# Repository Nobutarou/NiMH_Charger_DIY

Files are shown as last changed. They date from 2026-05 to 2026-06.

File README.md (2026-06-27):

# v6.0 チョッパー式というのに挑戦してみる。(回路図と図面に間違いあり)

## 注意

RL78/G24 の SDA と SDL の位置を反対にしてしまっている。
v6.1 で修正するつもり。本作は、その場でなんとか配線し直した。

## 内容

v5.0 で考えたことは全部が無駄というわけでも無さそうだ。実は、ダイオードで、p-MOS が閉じて
いるときの電流を GND に長さずに回収して、入口に流しこむことで、効率が上がるらしい。チョッ
パー型の DCDC の原理だそうだ。回生エナジーを上手く使おうということだな。

ということで Falstad での練習が [こちら](./v6.0/falstad.txt)。
PWM は RL78/G24 を 16MHz 駆動にして 1000カウントで 16kHz で考えてる。2^n よりも多分、計算
しやすそうなので。

コイルはサガミ RTP8010-330M の予定。Falstad のコイルには抵抗は無いので自分で入れる。0.086
Ωとのこと。Elshop で TDK TSL1112RA-330K2R3 がセール対象で心魅かれるが、普段からほほコイル
を使ったことがなく33uH がどれくらい汎用性があるのかも分からないので、見送る。こちらの抵抗
は 標準値は不明だが最大で0.062Ω。サガミの 7313NC-330M は高性能だが、さすがにでかすぎる。

ショットキーは [11EQS03L](https://akizukidenshi.com/catalog/g/g108997/) で、逆飽和電流を
0.45V と 0.4V のときの T=25℃での電流値に、おおよそ合せ込んである。

pMOS は [2SJ334](https://akizukidenshi.com/goodsaffix/2sj334.pdf) で
βは単純な二次式による近似なので、データシートの全部に一致することはない。データシートは派
手な数値ばかり記載されているが、自分が欲しい 1A あたりのデータは、データシート 3ページ目の
左上 ID-VDS プロットである。ここから 

| VGS[V] | VDS[V] | ID[I] |
| --- | --- | --- |
| 2.5 | 0.135 | 1.0 |
| 3.0 | 0.06 | 1.0|

が得られる。Falstad の式では Vth 以下では電流が 0 になるので、ここはエイヤーで Vth=-1.4V
とした。それに対して β=8.35 となった。
[Falstad回路](./v6.0/2SJ334_falstad.txt)

一番右端のコンデンサは、パスコン。
ADC の C が 5pF と仮定する。インピーダンスは C に反比例。パスコンを入れて並列にしたら、そ
の比率でインピーダンスが低い方に流れる。

一方、ADC は 4096分解能。つまり,1波で 4096カウント分のノイズが入ったとしても、ノイズを
1/4096 まで減らせば 1カウントの誤差にまで減らせる。1/40960 まで減らせば 0.1 カウントだ。

そして 5pF の 40960倍 = 0.2uF だ。つまり 0.22uF で良いだろう。Falstad でも 0.1Ωのところの
電圧は安定しているように見える。そもそも ADC にパスコンなんて入れたこともないし、悪くなる
ことは無いだろう。

Fasltad で 1A を狙うようにデューティ比を調整しながら、電流や消費電力を測ってみた。
[計算シート](./v6.0/calc.gnumeric)

そしてDuty% (D), 電池電圧 (Vb), 電流(I) について、以下の近似式を得た。

```math
D = 87.382624  -26.930792 Vb -5.5315597 I 
``` 

今回 I=1A を狙っているので、

```math
D = 81.851064  -26.930792 Vb
```

が得られる。

どうせこの通りにはならないので、電流 (0.1Ωの電圧) が足りなければ 1カウント-, 越えてれば 1
カウント+ みたいに補正値を与えれば良いだろう。

[回路図](./v6.0/NiMHCharger6.0/NiMHCharger6.0_Schematics.pdf)

[設計図](./v6.0/NiMHCharger6.0.pdf)

部品表:

| 記号 | 品番、品目 | 個数 |
| --- | --- | --- |
| B1 | ユニバーサル基板 12x11P | 1 |
| B2 | ユニバーサル基板 15x10P | 1 |
| B2 | ユニバーサル基板  5x1P  | 1 |
| C1 | ケミコン 220uF | 1 |
| C2-4  | セラコン 0.22uF | 3 |
| D1 | ショットキー 1A 以上 | 1 |
| D2 | LED | 1 |
| H1 | 低背ヘッダ 2P | 1 |
| H2 | ヘッダ 5P | 1 |
| H3,4  | ヘッダ 3P | 2 |
| H5-7  | ヘッダ 1P | 3 |
| H8-10 | ヘッダ 2P | 3 |
| J1 | 電池ボックス 単三 基板用 | 1 |
| L1 | 33uH | 1 |
| Q1 | 2SJ334 pMOS | 1 |
| R1 | 0.1Ω 1% 0.25W 以上 | 1 |
| R2 | 100kΩ | 1 |
| R3,4  | 1kΩ | 1 |
| R5,6  | 300Ω | 1 |
| R7 | 2.7kΩか 1kΩか | 1 |
| S1 | プッシュスイッチ NKK の | 1 |
| S2 | ソケット 5P | 1 |
| TP1 | チェック端子 | 1 |
| U2 | TA76L431S | 1 |
| X1 | XH ポスト 2P | 1 |

## 結果

まずダメだったところ。3.3V では 5V の LCD は動かない。ソースは LCD の有無を選択できるよう
にした。

あと、マイコンの書き込みの時に配線つなぎ変えるのサボってやらかした。マザボがダメージを負っ
たらしく、USB の電圧がかなり落ちてしまった。この手の失敗は時々するので、USB ハブは別電源か
ら取れる準備をした方が良さそう。

それ以外は多分うまくいった。

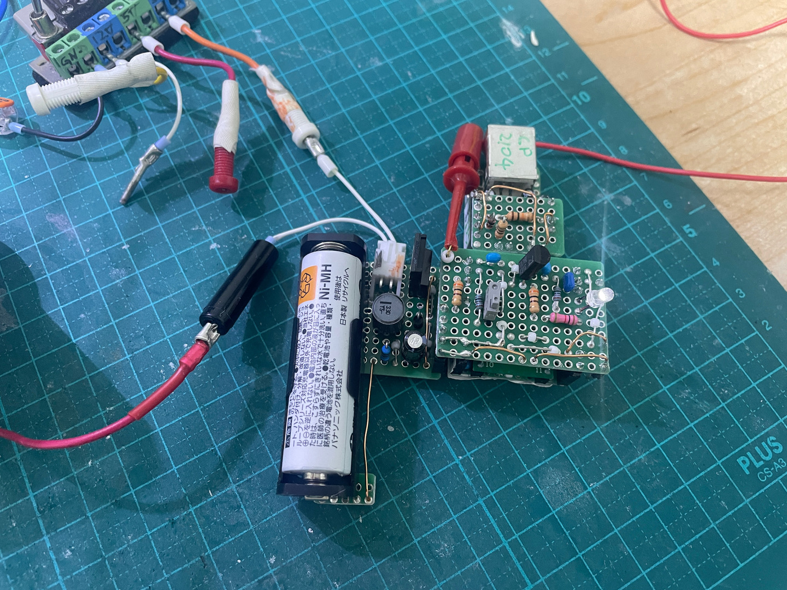
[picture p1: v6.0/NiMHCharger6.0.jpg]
完成品


電圧の垂れ下がりをうまくキャッチ。最序盤の急上昇の後の不安定さも移動平均でカバーできている
みたい。

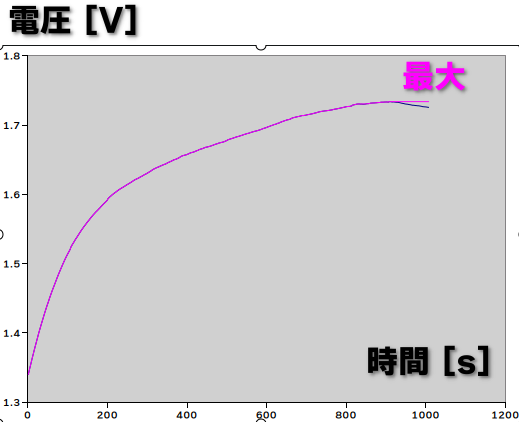
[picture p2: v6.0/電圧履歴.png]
電圧履歴


電流もおおよそ 1A をキープ。

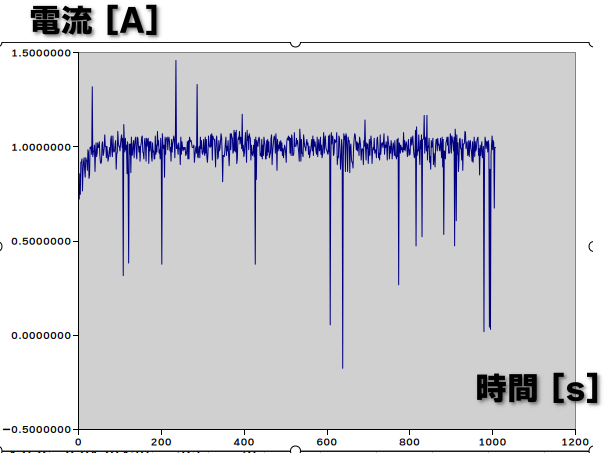
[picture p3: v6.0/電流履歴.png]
電流履歴


Duty の補正もまずまずの大きさ。Duty が振動してるのは、本来それだけ ADC の値が振動していた
ということ。移動平均が良い仕事をしたことが、ここからも分かる。

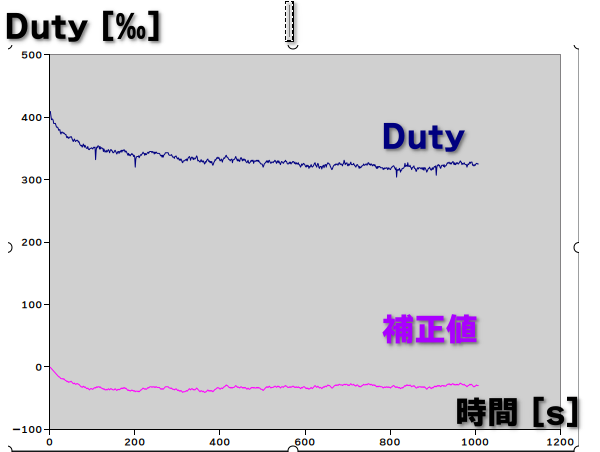
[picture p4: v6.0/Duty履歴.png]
Duty履歴


## ファームウェアの修正

電池によっては、初期の偽最大電圧からの下りを 84 秒以内にリカバリーできない。観察していると、
ガッと下がったあと、上昇基調で挽回しようとはするけど 84秒に到達という感じなので、一定回数、
10回とか、上昇基調が続いたら、偽最大電圧と判定して、その時点の電圧に最大値を置き換えるよう
にしてみる。

# v5.0 （没)
 <!--  {{{ -->
[こちら](https://github.com/Nobutarou/ArduinoDeAsobu/tree/main/NiMH_Charger)
で制作してきたが、リポジトリ自体がかなり大きくなってきたので、こっちに移った。そっちで検討
していた V4.0 は、なんだか苦労する割に報われない気がしたのでやめた。

v3.0 の改良を測ってみる。v3.0 の弱点は

- 充電中の電池電圧を測っていない
  - PWM でパチパチやってるときに、電圧測っちゃだめな気がしたため
- NchMOSFET を使ったため、電池の底の電圧を測定したが、多分これが精度低すぎ。
- 1A を狙ったが、実際には 70% くらいだった。

[こちら](https://github.com/Nobutarou/ArduinoDeAsobu/tree/main/LiIonCharger) 
ではリチウムイオン電池を充電してみたが、この時は PchMOSFET を使い、電池の頭の電圧を測定し
たが、値は安定しているように思う。

なので、今回は、PchMOSFET を使って LC フィルタで「まあこれなら電圧測っても大丈夫くらいだろ
う」と思える程度まで平滑化してみたい。平滑化するには PWM を極力高周波数で回すことが大事な
ので、RL78/G24 の最大32MHz 駆動で、99 または 255 カウントあたりの PWM, 周波数にして
125k-320kHz を使いたい。

li-ion のときの 
[2SJ334](https://akizukidenshi.com/goodsaffix/2sj334.pdf)
が 100kHz 台のパチパチに耐えられるかがポイント。

Vgs=-10V で Qg=110nC とあるので、Ciss=11000pF を採用したときのシミュレーションをする。
Falstad の P-mos の βは

```math
\beta = \frac{Y_{fs} }{Vgs-Vth}
```

Yfs が無いときは
```math
\beta = \frac{1}{R_{DS(on)} (V_{GS} - V_{th})}
```

でやってみると、そもそも理想状況でも全然電圧がでない。コイルは交流成分からしたら抵抗だから、
電圧がぐっと下がってどうにもならない。
https://x.gd/wddPF

そもそも構造的欠陥。

でコイルを止めてショットキーを入れるとなんか整流できてる。
https://x.gd/BBFU5

C で決まるローパスの周波数はこうらしい。手持ちだと 220uF が丁度良い感じ。PWM の切替えも数
百 usec で落ち着くかんじ。
```math
fc = \frac{1}{2 \pi R C}
```

で Ciss=11000pF 入れると全然だめ。オンにできないようだ。125kHz に落としてもどうにもならな
い。逆に 220uF は 125kHz でも良い感じでフィルタできる。

ところでダイオードを入れたが 0.47Ωの R を 2個の 0.22Ωに分けても良いみたいだ。ただどのみ
ち Ciss=11000pF ではどうにもならない。あと PWM を 64kHz とかにすると 220uF でも足りなくな
りがち。
https://x.gd/201CP

さて Ciss だけど実は Ciss(Vgs=0V)=3300pF, Ciss(Vgs=10V)=11000pF である。なので、3300pF で
成立しなかったら、もうどうにもならない。Ciss 無しで 1.65V くらいのようだが、3300pF を入れ
ると、1.42V くらいまで下がってしまう。

ただ 3.3V ではどうだろうか。Ciss(Vgs) は凸な関数と Gemini が言ってるので、なんとなく、
```math
a+b Vgs ^n
``` 
みたいな Johnson-cook な感じが合うような気がする。
次元がおかしいので Vgs は電圧ではなく、基準電圧との比率とすべきだが、細かいことはいいだろ
う。
a=Ciss(Vgs=0) で良いが b と n は分かりよ
うがないので、とりあえず n=0.5 とする。b=2435[pF] となる。
この仮定だと Ciss(Vgs=3.3V)=7723pF である。はい、全然だめ。

では 
[2SJ496](https://akizukidenshi.com/goodsaffix/2sj496.pdf) 
はどうだろうか。Yfs=5, Vth=2, Vgs(ID=2.5A)=2.7Vくらい（ID-Vgs プロットから) なので β=7.14
Ciss に最小値の 600pF の 2.34 倍, 1404pF を入力してみる。Qgs が載ってないから超適当.
で 1.4V くらいは出る。

だめだ。この方法は無理だ。最初の PWM を直接当ててる方がまだまし。

<!-- }}} -->

というか、何をどうしようが、3.3V 電源から 1A 流す時点で全体の消費電力は 3.3W。電池が 1V の
時は 2.3W を捨てて、電池が 1.5V のときは 1.8W を捨ててると言うこと。

P-mos から電池までの間をどうしようが、電力消費するパートがどれになるか変わるだけで、効率は
変わらない。

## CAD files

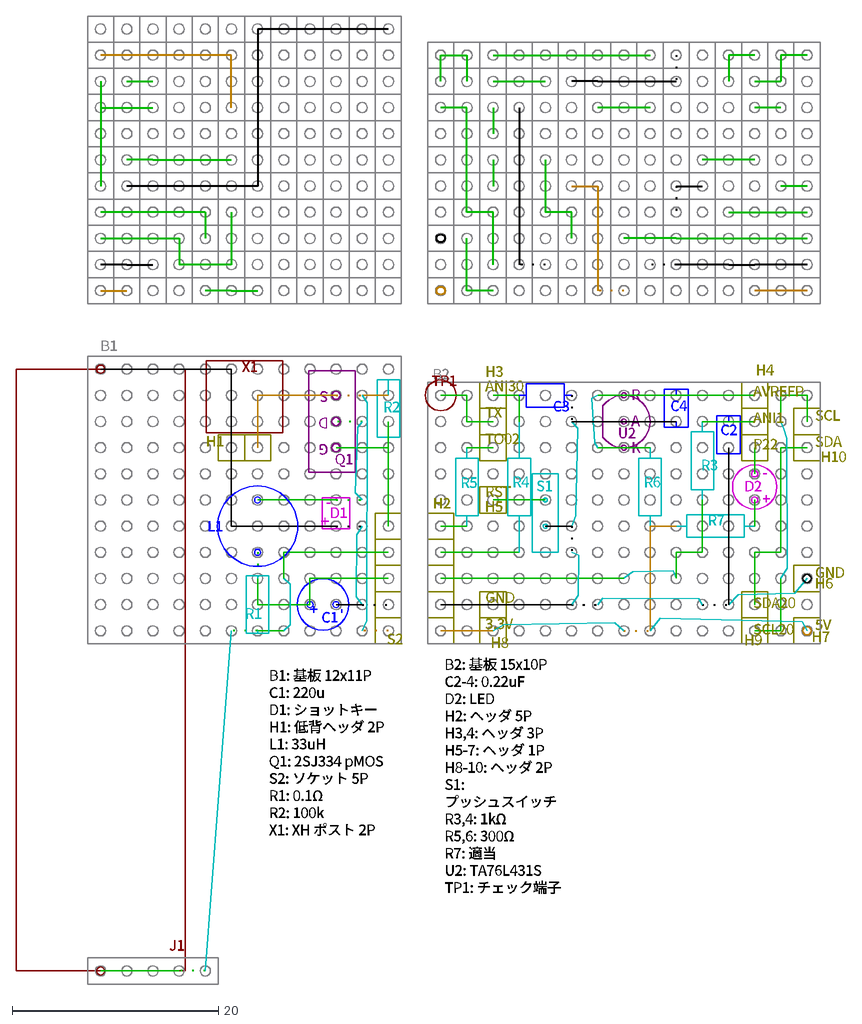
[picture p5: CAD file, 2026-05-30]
v6.0/NiMHCharger6.0.dxf
G D S
+
-
ANI30 TX TO02 RST GND 3.3V
R A K
- +
5V
GND
SDA
SCL
S1
B1
J1
X1
H1
L1
C1
D1
Q1
R2
H2
B2
H3
H4
H5
R5
U2
C4
R6
R3
C2
H6
H7
H8
H9
H10
R7
R1
R4
+ -
C3
TP1
AVREFP ANI1 P22 SDA20 SCL20
D2
B2: 基板 15x10P C2-4: 0.22uF D2: LED H2: ヘッダ 5P H3,4: ヘッダ 3P H5-7: ヘッダ 1P H8-10: ヘッダ 2P S1: プッシュスイッチ R3,4: 1kΩ R5,6: 300Ω R7: 適当 U2: TA76L431S TP1: チェック端子
S2
B1: 基板 12x11P C1: 220u D1: ショットキー H1: 低背ヘッダ 2P L1: 33uH Q1: 2SJ334 pMOS S2: ソケット 5P R1: 0.1Ω R2: 100k X1: XH ポスト 2P

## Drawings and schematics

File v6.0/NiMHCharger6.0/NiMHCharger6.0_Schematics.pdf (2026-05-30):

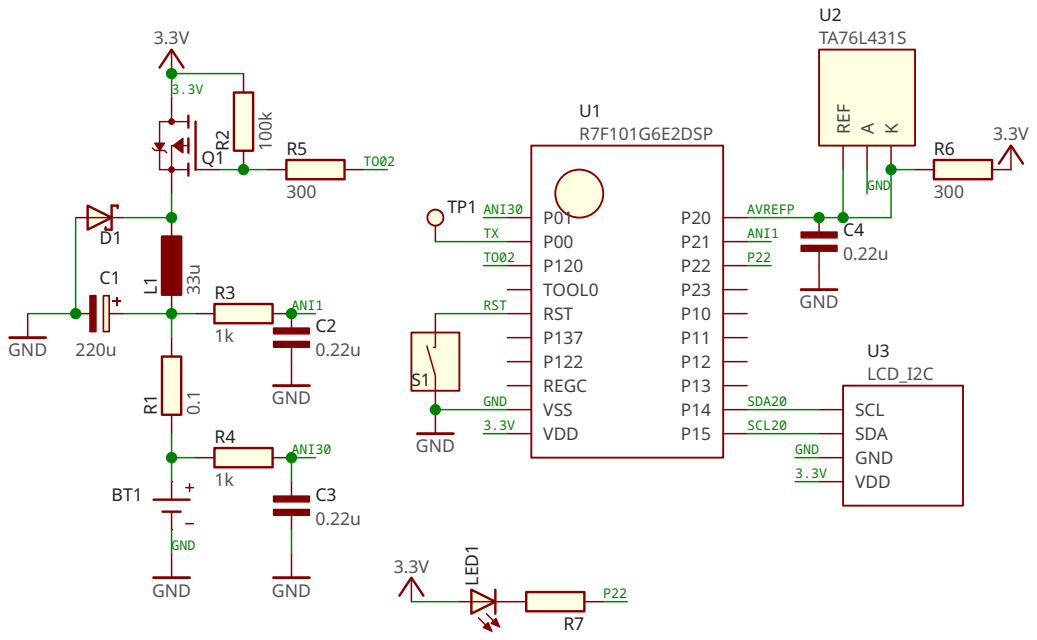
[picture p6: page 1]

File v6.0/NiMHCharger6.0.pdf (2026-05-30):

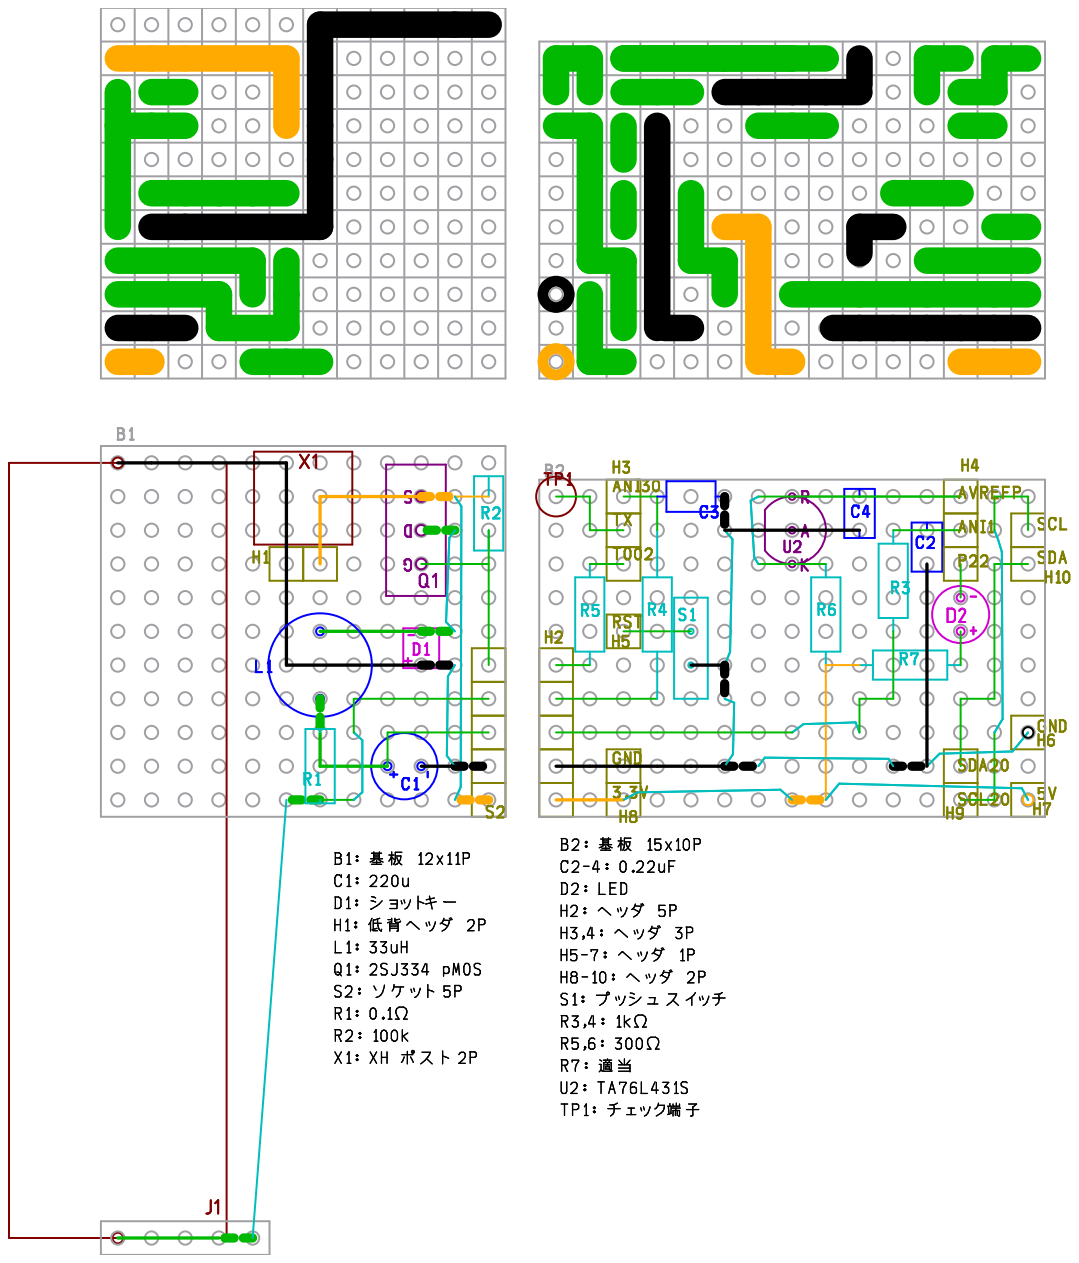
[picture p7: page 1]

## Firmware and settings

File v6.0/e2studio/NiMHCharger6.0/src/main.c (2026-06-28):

/*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
* Copyright (C) 2020 Renesas Electronics Corporation. All rights reserved.
***********************************************************************************************************************/

/***********************************************************************************************************************
*  File Name    : LCD_Hello.c
*  Description  : Main Program
*  Creation Date: 2025-10-12
*  This file was generated by Smart Configurator.
***********************************************************************************************************************/

#include "r_smc_entry.h"

int main(void);

// UART, I2C
volatile uint8_t _i2c_send_end; // 送信完了フラグ
volatile uint8_t _uart_end; 
#include "OreLCD.c" // _i2c_send_end と _uart_end は必要

#define DEBUG 1 //0: しない, 1: 軽く, 2: ガチ
#define USE_LCD 0 // 0: 未使用, 1:使う
// Gemini によると、最近のコンパイラは優秀なので static const でメモリを消費することは無い
// と言ってる。試しに #define ではなく static const で書いてみる。
// 可読性が良い気がする。
// それから static は、この .c でのみ有効という意味

static const float vref = 2.49; //ADC参照電圧
static const uint16_t pwm_count = 1000;
// 実際には 0-999 で一周期。RL78/G24 は 1000 を入れれば 100% になる。はず。

static const float duty_const = 81.851064; 
static const float tan_duty = -26.930792;
// D = 81.851064  -26.930792 Vb

static const uint8_t sub_count_max = 64;
// max712 の 1 サイクル 84 秒の間に行う子サイクルに相当

static const uint8_t main_count_max = 132*60/84;
// max712 は 132分でタイムオーバー。

static const uint16_t sub_wait_ms = 84000/64 ;
// max712 の 1サイクル[ms] に 2^sub_count_max 回、子サイクルを回すので、そのウェイト

static float rref = 0.1; //電圧測定抵抗 
static float sma_alfa = 1.0/64.0 ;//SMA移動平均の係数

static float current_target_upper = 1.02; //電流目標上限
static float current_target_lower = 0.98; //電流目標上限
// dI/dDuty[‰]=-0.018A。1A ターゲットなら、おおよそ 2%

// 移動平均電圧が、この回数連続で上昇したら、その最大電圧は序盤の偽最大値と判断して、その
// 時点の移動平均電圧に置き換える。
// 10 だと厳しすぎた感じ。
// static uint8_t nise_max_kaijo_count =5;
// これを使わない方法にしてみた。

int main(void)
{
  float vbat; //電池電圧
  float vbat_sma; //電池電圧 SMA 移動平均
  float vbat_sma_max; // SMA最大値
  int duty; //PWM Duty。計算の都合上 int にしておく
  
  uint8_t sub_count = 1;
  //max712 での 1サイクル内でのカウント
  //便宜上 1から始める
  uint8_t main_count = 1;

  float vr; //抵抗電圧
  float current; //電流

  uint8_t flag_max=0; 
  //最大電圧更新フラグ. 1 で更新

  int duty_hosei=0; //Duty の補正オフセット量

  // 偽 max を判定するための、vbat_sma 連続上昇回数カウント
  //uint8_t renzoku_up_count = 0;
  float vbat_sma_pre; //電池電圧 SMA 移動平均、1サイクル前

  EI();

  // LED 点灯
  // プルアップなので 0 で点灯
  P2_bit.no2 = 0;

  // PWM を開始。コンフィグレータで 1000‰に指定してある。
  R_Config_TAU0_0_Start()  ;

  #if DEBUG >= 1
  R_Config_UART1_Start();
  // OreUART1_Send_ASCII('S'); // OK
  #endif 

  #if USE_LCD == 1
  OreLCDBegin();    
  #endif 

  #if DEBUG >= 1
  //OreUART1_Send_ASCII('L'); // NG
  //OreUART1_Send_CRLF();
  // SDA と SCL を逆にしてしまう大失敗。--> 直した
  // なぜかここに戻ってきてしまう。
  #endif 

  // ADC 空打ち
  // なんか起動直後の 1回目は変な値を取る気がする。
  // コンフィグレータ設定ピンは ANI30
  R_Config_ADC_Start();
  while(ADCS==1){};
  R_Config_ADC_Stop();
  // ANI1 に切り替えて空打ち
  R_Config_ADC_Set_ADChannel (ADCHANNEL1);
  R_Config_ADC_Start();
  while(ADCS==1){};
  R_Config_ADC_Stop();
  // ANI30 に戻す
  R_Config_ADC_Set_ADChannel (ADCHANNEL30);

  // ここからが本番
  // ADC の測定
  // 今 ANI30, 電池になってる
  R_Config_ADC_Start();
  while(ADCS==1){};
  R_Config_ADC_Stop();
  vbat = vref * ( (float)ADCR0+0.5 )/4096.0;
  // 回してる最中なら ANI1 に切り替えて抵抗の電圧を測定するが 1回目なので何もしない。
  
  // 最初の計測値で SMA 電圧を埋めておく。一回目だけ。
  vbat_sma = vbat;
  vbat_sma_max = vbat_sma;

  // 目標Duty の決定
  duty = (int)( (duty_const + tan_duty * vbat)/100.0 * (float)(pwm_count) ) ;
  if (duty > pwm_count){ 
    duty = pwm_count;
  } else if (duty < 0){
    duty = 0;
  }
  TDR02=(uint16_t)duty;

  // 電池電圧、電流、Duty補正をUART に出すことにしておこう。

  // LCD も同様
  #if USE_LCD == 1
  OreLCD_Char(0b01010110); //"V"
  OreLCD_Char(0b00111010); //":"
  OreLCD_Fixed(vbat, 4);
  OreLCD_Locate(1,0); //二行目
  OreLCD_Char(0b01001001); //"I"
  OreLCD_Char(0b00111010); //":"
  #endif 

  #if DEBUG >= 1
  // ここは表示される。
  OreUART1_Send_Float(vbat_sma, 8);
  OreUART1_Send_ASCII(',');
  OreUART1_Send_CRLF();
  #endif 

  //sub_count=sub_count+1; 

  R_BSP_SoftwareDelay(sub_wait_ms, BSP_DELAY_MILLISECS);

  // これで子サイクルの 1回目が終わった。

  // メインサイクル
  for(; main_count <= main_count_max; main_count++){
    // サブサイクル
    for (; sub_count <= sub_count_max; sub_count++){
      //{{{
      //電池電圧測定
      R_Config_ADC_Set_ADChannel (ADCHANNEL30);
      R_Config_ADC_Start();
      while(ADCS==1){};
      R_Config_ADC_Stop();
      vbat = vref * ( (float)ADCR0+0.5 )/4096.0;
    
      //抵抗電圧測定
      R_Config_ADC_Set_ADChannel (ADCHANNEL1);
      R_Config_ADC_Start();
      while(ADCS==1){};
      R_Config_ADC_Stop();
      vr = vref * ( (float)ADCR0+0.5 )/4096.0;

      //移動平均、最大値チェック
      vbat_sma_pre = vbat_sma;
      vbat_sma = vbat * sma_alfa + (1.0-sma_alfa) * vbat_sma;
      
      //if (vbat_sma > vbat_sma_max){
      //// 最大値更新したとき
      //  vbat_sma_max = vbat_sma;
      //  flag_max = 1;
      //  renzoku_up_count = 0;
      //} else if (vbat_sma > vbat_sma_pre) {
      //// 最大値は更新しなかったが、vbat_sma 自体は 1サブサイクル前を越えてる場合
      //  renzoku_up_count = renzoku_up_count + 1;
      //  if (renzoku_up_count >= nise_max_kaijo_count){
      //  // 連続 nise_max_kaijo_count 回の上昇を示したら
      //    vbat_sma_max = vbat_sma;
      //    flag_max = 1;
      //    renzoku_up_count = 0;
      //  };
      //} else {
      //// 最大値も更新しないし vbat_sma も前サイクルに及ばないなら
      //  renzoku_up_count = 0;
      //}

      // 更新しなくても上昇していれば vbat_sma_max を現在地との平均値とする。
      if (vbat_sma > vbat_sma_max){
      // 最大値更新したとき、そのまま置き換え。
        vbat_sma_max = vbat_sma;
        flag_max = 1;
      } else if (vbat_sma > vbat_sma_pre) {
      // 最大値は更新しなかったが、vbat_sma 自体は 1サブサイクル前を越えてる場合
          vbat_sma_max = 0.5*vbat_sma + 0.5*vbat_sma_max;
      };

      //電流計算
      current = (vr-vbat)/rref;

      // dI/dDuty = -0.18 A/duty[%] = -0.018A/duty[‰]
      // つまり 0.018A のずれが無ければ、duty を触る価値はない
      // ざっくり 2% で見ておけばいいだろう。
      if (current > current_target_upper){
        duty_hosei=duty_hosei+1;
      } else if (current < current_target_lower ){
        duty_hosei=duty_hosei-1;
      };

      // 今回から duty に補正を掛ける
      duty = (int)( (duty_const + tan_duty * vbat)/100.0 * (float)(pwm_count) ) + duty_hosei ;
      if (duty > pwm_count){ 
        duty = pwm_count;
      } else if (duty < 0){
        duty = 0;
      }

      TDR02=(uint16_t)duty;

      #if DEBUG >= 1
      // 途中で current を出力できなくなる
      OreUART1_Send_Float(vbat_sma, 8);
      OreUART1_Send_ASCII(',');
      OreUART1_Send_Float(vbat_sma_max, 8);
      OreUART1_Send_ASCII(',');
      //OreUART1_Send_Float(vbat, 8);
      //OreUART1_Send_ASCII(',');
      //OreUART1_Send_Float(vr, 8);
      //OreUART1_Send_ASCII(',');
      // なんか知らんけど current止まる. 
      OreUART1_Send_Float(current, 7);
      OreUART1_Send_ASCII(',');
      OreUART1_Send_U16( (uint16_t)duty);
      OreUART1_Send_ASCII(',');
      if( duty_hosei < 0){
        OreUART1_Send_ASCII('-');
        OreUART1_Send_U16( (uint16_t)(-duty_hosei) );
      } else {
        OreUART1_Send_U16( (uint16_t)(duty_hosei) );
      }
      OreUART1_Send_CRLF();
      #endif 

      // LCD も同様
      #if USE_LCD == 1
      OreLCD_CLS();
      OreLCD_Char(0b01010110); //"V"
      OreLCD_Char(0b00111010); //":"
      OreLCD_Fixed(vbat, 4);
      OreLCD_Locate(1,0); //二行目
      OreLCD_Char(0b01001001); //"I"
      OreLCD_Char(0b00111010); //":"
      OreLCD_Fixed(current, 4);
      #endif
      R_BSP_SoftwareDelay(sub_wait_ms, BSP_DELAY_MILLISECS);
    /* }}} */
    };
    if(flag_max == 0){
      TDR02=pwm_count;
      while(1){
         // LED チカチカ
         P2_bit.no2 = !P2_bit.no2;
         R_BSP_SoftwareDelay(1, BSP_DELAY_SECS);
      };
    }
    sub_count=1;
    flag_max = 0;
  }

  // メインカウント乗り越えたら
  TDR02=pwm_count;
  while(1){
     // LED チカチカ
     P2_bit.no2 = !P2_bit.no2;
     R_BSP_SoftwareDelay(2, BSP_DELAY_SECS);
  };
  return 0;
}

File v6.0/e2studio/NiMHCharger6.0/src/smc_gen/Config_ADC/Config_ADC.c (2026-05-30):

/*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
* Copyright (C) 2021, 2025 Renesas Electronics Corporation. All rights reserved.
***********************************************************************************************************************/

/***********************************************************************************************************************
* File Name        : Config_ADC.c
* Component Version: 1.8.0
* Device(s)        : R7F101G6ExSP
* Description      : This file implements device driver for Config_ADC.
***********************************************************************************************************************/

/***********************************************************************************************************************
Pragma directive
***********************************************************************************************************************/
/* Start user code for pragma. Do not edit comment generated here */
/* End user code. Do not edit comment generated here */

/***********************************************************************************************************************
Includes
***********************************************************************************************************************/
#include "r_cg_macrodriver.h"
#include "r_cg_userdefine.h"
#include "Config_ADC.h"
/* Start user code for include. Do not edit comment generated here */
/* End user code. Do not edit comment generated here */

/***********************************************************************************************************************
Global variables and functions
***********************************************************************************************************************/
/* Start user code for global. Do not edit comment generated here */
/* End user code. Do not edit comment generated here */

/***********************************************************************************************************************
* Function Name: R_Config_ADC_Create
* Description  : This function initializes the ADC module.
* Arguments    : None
* Return Value : None
***********************************************************************************************************************/
void R_Config_ADC_Create(void)
{
    ADCEN = 1U;    /* supply AD clock */
    ADMK0 = 1U;    /* disable INTAD0 interrupt */
    ADIF0 = 0U;    /* clear INTAD0 interrupt flag */
    /* Set INTAD0 priority */
    ADPR10 = 1U;
    ADPR00 = 1U;
    /* Set ANI30 pin */
    PMCA0 |= 0x02U;
    PM0 |= 0x02U;
    /* Set AVREFP pin */
    PMCA2 |= 0x01U;
    PM2 |= 0x01U;
    ADM0 = _00_AD_OPERMODE_SELECT | _18_AD_CONVERSION_CLOCK_4 | _00_AD_TIME_MODE_NORMAL_1;
    ADM1 = _00_AD_TRIGGER_SOFTWARE | _00_AD_FCLK_BETWEEN_4_48 | _20_AD_CONVMODE_ONESELECT;
    ADM2 = _00_AD_NEGATIVE_VSS | _00_AD_AREA_MODE_1 | _02_AD_RESOLUTION_12BIT;
    ADUL = _FF_AD_ADUL_VALUE;
    ADLL = _00_AD_ADLL_VALUE;
    ADS = _1E_AD_INPUT_CHANNEL_30;
    ADM2 &= _3F_AD_POSITIVE_CLEAR;    /* clear ADREFP1 and ADREFP0 */
    ADM2 |= _40_AD_POSITIVE_AVREFP;    /* set the reference voltage */

    R_Config_ADC_Create_UserInit();
}

/***********************************************************************************************************************
* Function Name: R_Config_ADC_Start
* Description  : This function starts the AD converter.
* Arguments    : None
* Return Value : None
***********************************************************************************************************************/
void R_Config_ADC_Start(void)
{
    ADIF0 = 0U;    /* clear INTAD0 interrupt flag */
    ADMK0 = 0U;    /* enable INTAD0 interrupt */
    ADCS = 1U;    /* enables conversion operation */
}

/***********************************************************************************************************************
* Function Name: R_Config_ADC_Stop
* Description  : This function stops the AD converter.
* Arguments    : None
* Return Value : None
***********************************************************************************************************************/
void R_Config_ADC_Stop(void)
{
    ADCS = 0U;    /* stops conversion operation */
    ADMK0 = 1U;    /* disables INTAD0 interrupt */
    ADIF0 = 0U;    /* clear INTAD0 interrupt flag */
}

/***********************************************************************************************************************
* Function Name: R_Config_ADC_Set_OperationOn
* Description  : This function enables AD voltage comparator operation.
* Arguments    : None
* Return Value : None
***********************************************************************************************************************/
void R_Config_ADC_Set_OperationOn(void)
{
    volatile uint16_t w_count;

    ADCE = 1U;    /* enable AD comparator */

    /* Reference voltage stability wait time (B) 1us */
    for (w_count = 0U; w_count < AD_WAITTIME_B; w_count++ )
    {
        NOP();
    }
}
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

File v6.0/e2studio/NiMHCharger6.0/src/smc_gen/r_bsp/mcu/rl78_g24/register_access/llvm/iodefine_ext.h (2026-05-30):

/*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
* Copyright (C) 2023 Renesas Electronics Corporation. All rights reserved.
***********************************************************************************************************************/
/***********************************************************************************************************************
* File Name    : iodefine_ext.h
* Description  : 
***********************************************************************************************************************/
/***********************************************************************************************************************
* History : DD.MM.YYYY Version  Description
*         : 28.02.2023 1.60     First Release.
*         : 30.11.2023 1.62     Updated device file.
***********************************************************************************************************************/

#ifndef __INTRINSIC_FUNCTIONS
#define __INTRINSIC_FUNCTIONS

#define DI() __builtin_rl78_di()
#define EI() __builtin_rl78_ei()
#define HALT() __halt()
#define NOP() __nop()
#define STOP() __stop()

#endif

#ifndef __IOREG_BIT_STRUCTURES
#define __IOREG_BIT_STRUCTURES
typedef struct {
	unsigned char no0 :1;
	unsigned char no1 :1;
	unsigned char no2 :1;
	unsigned char no3 :1;
	unsigned char no4 :1;
	unsigned char no5 :1;
	unsigned char no6 :1;
	unsigned char no7 :1;
} __BITS8;

typedef struct {
	unsigned short no0 :1;
	unsigned short no1 :1;
	unsigned short no2 :1;
	unsigned short no3 :1;
	unsigned short no4 :1;
	unsigned short no5 :1;
	unsigned short no6 :1;
	unsigned short no7 :1;
	unsigned short no8 :1;
	unsigned short no9 :1;
	unsigned short no10 :1;
	unsigned short no11 :1;
	unsigned short no12 :1;
	unsigned short no13 :1;
	unsigned short no14 :1;
	unsigned short no15 :1;
} __BITS16;

#endif

#ifndef IODEFINE_EXT_H
#define IODEFINE_EXT_H

/*
 IO Registers
 */
union un_adm2 {
	unsigned char adm2;
	__BITS8 BIT;
};
union un_adm3 {
	unsigned char adm3;
	__BITS8 BIT;
};
union un_adsctl {
	unsigned char adsctl;
	__BITS8 BIT;
};
union un_adintctl {
	unsigned char adintctl;
	__BITS8 BIT;
};
union un_adintst {
	unsigned char adintst;
	__BITS8 BIT;
};
union un_pu0 {
	unsigned char pu0;
	__BITS8 BIT;
};
union un_pu1 {
	unsigned char pu1;
	__BITS8 BIT;
};
union un_pu3 {
	unsigned char pu3;
	__BITS8 BIT;
};
union un_pu4 {
	unsigned char pu4;
	__BITS8 BIT;
};
union un_pu5 {
	unsigned char pu5;
	__BITS8 BIT;
};
union un_pu6 {
	unsigned char pu6;
	__BITS8 BIT;
};
union un_pu7 {
	unsigned char pu7;
	__BITS8 BIT;
};
union un_pu12 {
	unsigned char pu12;
	__BITS8 BIT;
};
union un_pu14 {
	unsigned char pu14;
	__BITS8 BIT;
};
union un_pim0 {
	unsigned char pim0;
	__BITS8 BIT;
};
union un_pim1 {
	unsigned char pim1;
	__BITS8 BIT;
};
union un_pim3 {
	unsigned char pim3;
	__BITS8 BIT;
};
union un_pim5 {
	unsigned char pim5;
	__BITS8 BIT;
};
union un_pim7 {
	unsigned char pim7;
	__BITS8 BIT;
};
union un_pom0 {
	unsigned char pom0;
	__BITS8 BIT;
};
union un_pom1 {
	unsigned char pom1;
	__BITS8 BIT;
};
union un_pom3 {
	unsigned char pom3;
	__BITS8 BIT;
};
union un_pom5 {
	unsigned char pom5;
	__BITS8 BIT;
};
union un_pom7 {
	unsigned char pom7;
	__BITS8 BIT;
};
union un_pmca0 {
	unsigned char pmca0;
	__BITS8 BIT;
};
union un_pmca1 {
	unsigned char pmca1;
	__BITS8 BIT;
};
union un_pmca2 {
	unsigned char pmca2;
	__BITS8 BIT;
};
union un_pmca12 {
	unsigned char pmca12;
	__BITS8 BIT;
};
union un_pmca14 {
	unsigned char pmca14;
	__BITS8 BIT;
};
union un_nfen0 {
	unsigned char nfen0;
	__BITS8 BIT;
};
union un_nfen1 {
	unsigned char nfen1;
	__BITS8 BIT;
};
union un_isc {
	unsigned char isc;
	__BITS8 BIT;
};
union un_ulbs {
	unsigned char ulbs;
	__BITS8 BIT;
};
union un_pms {
	unsigned char pms;
	__BITS8 BIT;
};
union un_pfber {
	unsigned char pfber;
	__BITS8 BIT;
};
union un_gdidis {
	unsigned char gdidis;
	__BITS8 BIT;
};
union un_dflctl {
	unsigned char dflctl;
	__BITS8 BIT;
};
union un_pckc {
	unsigned char pckc;
	__BITS8 BIT;
};
union un_flmode {
	unsigned char flmode;
	__BITS8 BIT;
};
union un_flmwrp {
	unsigned char flmwrp;
	__BITS8 BIT;
};
union un_fsse {
	unsigned char fsse;
	__BITS8 BIT;
};
union un_pfs {
	unsigned char pfs;
	__BITS8 BIT;
};
union un_per0 {
	unsigned char per0;
	__BITS8 BIT;
};
union un_prr0 {
	unsigned char prr0;
	__BITS8 BIT;
};
union un_osmc {
	unsigned char osmc;
	__BITS8 BIT;
};
union un_rpectl {
	unsigned char rpectl;
	__BITS8 BIT;
};
union un_porsr {
	unsigned char porsr;
	__BITS8 BIT;
};
union un_per1 {
	unsigned char per1;
	__BITS8 BIT;
};
union un_prr1 {
	unsigned char prr1;
	__BITS8 BIT;
};
union un_per2 {
	unsigned char per2;
	__BITS8 BIT;
};
union un_prr2 {
	unsigned char prr2;
	__BITS8 BIT;
};
union un_se0l {
	unsigned char se0l;
	__BITS8 BIT;
};
union un_ss0l {
	unsigned char ss0l;
	__BITS8 BIT;
};
union un_st0l {
	unsigned char st0l;
	__BITS8 BIT;
};
union un_soe0l {
	unsigned char soe0l;
	__BITS8 BIT;
};
union un_se1l {
	unsigned char se1l;
	__BITS8 BIT;
};
union un_ss1l {
	unsigned char ss1l;
	__BITS8 BIT;
};
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
